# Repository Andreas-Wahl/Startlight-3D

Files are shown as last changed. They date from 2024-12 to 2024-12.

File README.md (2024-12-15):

# STARTAMPEL "Bären(n)keller" 🚦

## Project Overview 🏎️

In a private cellar bar that has been in existence for over two generations, originally named "Bärenkeller," a CARRERA® digital 132 racetrack was set up, and the first races were held. This quickly gained popularity among friends and acquaintances. As a result, the racetrack was gradually expanded, and possible extensions were discussed.

The idea of creating a custom starting light emerged because the original CARRERA® Startlight (30354) could not bridge three lanes (two lanes + pit lane). Additionally, the custom STARTAMPEL should not only display the start sequence with red lights but also indicate the race operation with green LEDs, the safety car/pace car operation, and a false start.

The idea was quickly taken up, the data signal was analyzed with an oscilloscope and data logger, and the development of hardware, software, and housing design was initiated.

In reference to the "Bärenkeller," which was renamed "Bären(n)keller" due to the expansion of the CARRERA® digital 132 racetrack, the custom starting light was also named "STARTAMPEL 'Bären(n)keller'."

The STARTAMPEL "Bären(n)keller" was so well received that the developer decided to produce a small quantity as "prototypes" and make the development available for non-commercial use.

## Licensing 📜

- **Electronics and Housing Design**: Released under the Creative Commons Attribution-NonCommercial-ShareAlike 4.0 International License (CC BY-NC-SA 4.0).
- **Software**: Released under the GNU Affero General Public License, Version 3.0 (AGPL-3.0).

## Repository Contents 📂

- **3D CAD Models**: The complete 3D CAD models for the STARTAMPEL "Bären(n)keller".
- **STL Files**: STL files for 3D printing the components.

## Getting Started 🚀

To get started with the project, clone the repository and follow the instructions in the documentation to set up the hardware and software.

```bash
git clone https://github.com/Andreas-Wahl/Startlight-3D.git

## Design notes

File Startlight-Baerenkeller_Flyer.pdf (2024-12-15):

# SLOTCAR STARTAMPEL „Bären(n)keller“

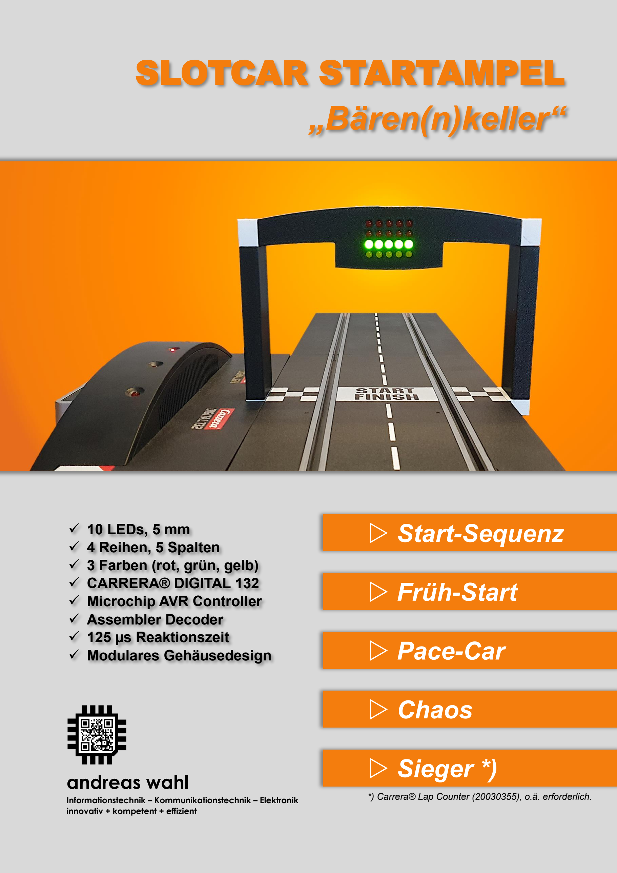
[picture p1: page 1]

# - Start-Sequenz

# - Früh-Start

# - Pace-Car

# - Sieger *)

# - Chaos

✓ 10 LEDs, 5 mm
✓ 4 Reihen, 5 Spalten
✓ 3 Farben (rot, grün, gelb) ✓ CARRERA® DIGITAL 132
✓ Microchip AVR Controller ✓ Assembler Decoder
✓ 125 µs Reaktionszeit
✓ Modulares Gehäusedesign

## andreas wahl

Informationstechnik – Kommunikationstechnik – Elektronik innovativ + kompetent + effizient

*) Carrera® Lap Counter (20030355), o.ä. erforderlich.

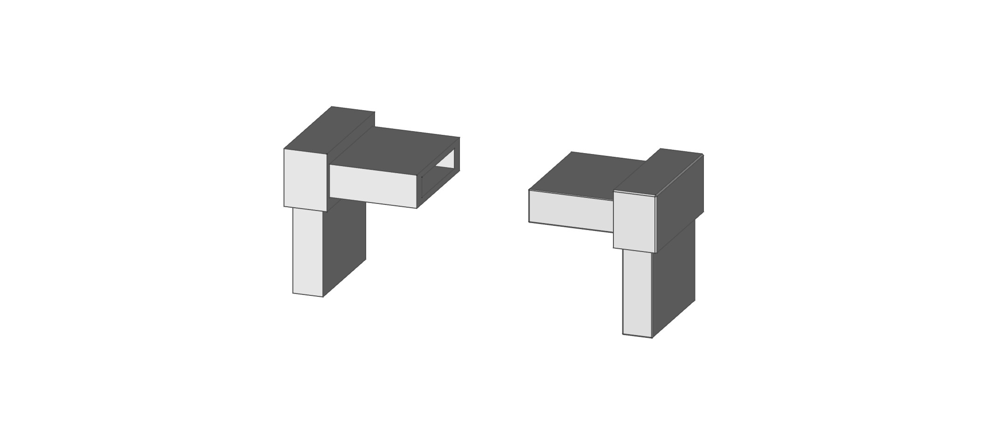
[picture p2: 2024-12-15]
#JPEG/Startlight-Baerenkeller_21_Winkel.jpeg

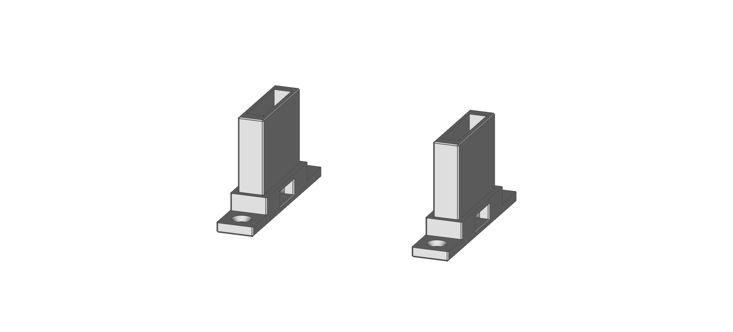
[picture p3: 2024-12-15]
#JPEG/Startlight-Baerenkeller_45_Fuesse_verschraubt.jpeg

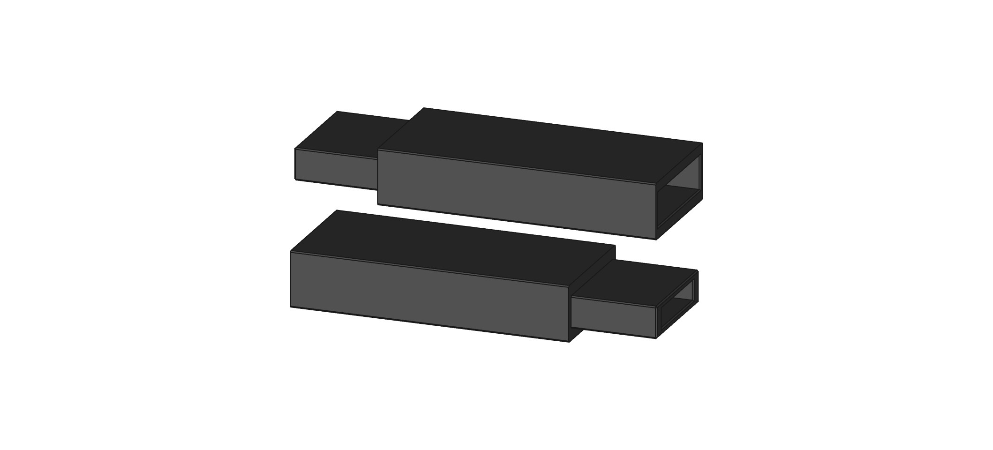
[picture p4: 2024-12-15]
#JPEG/Startlight-Baerenkeller_23_Verlaengerungen.jpeg

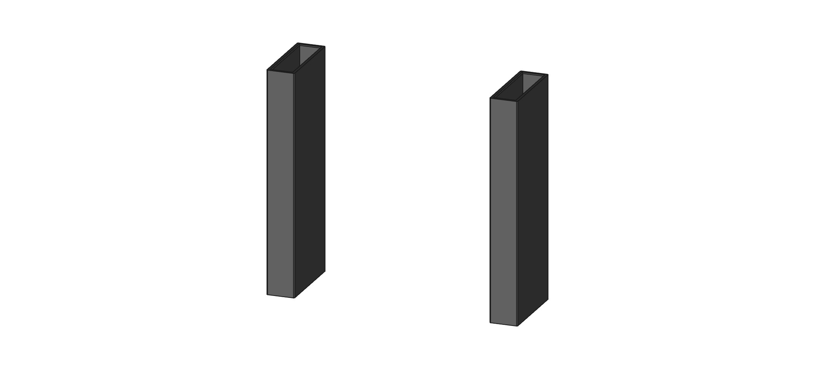
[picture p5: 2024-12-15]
#JPEG/Startlight-Baerenkeller_31_Saulen.jpeg

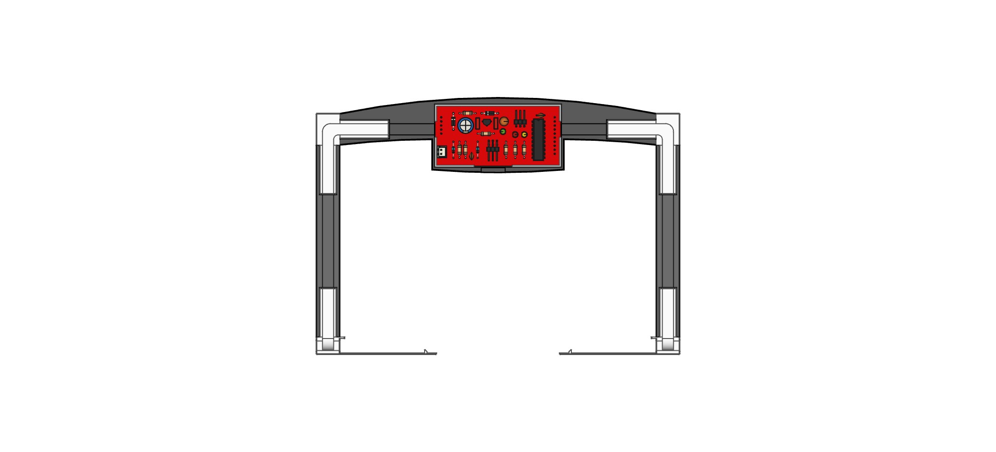
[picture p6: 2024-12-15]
#JPEG/Startlight-Baerenkeller_02_Schnitt_Rueckseite.jpeg

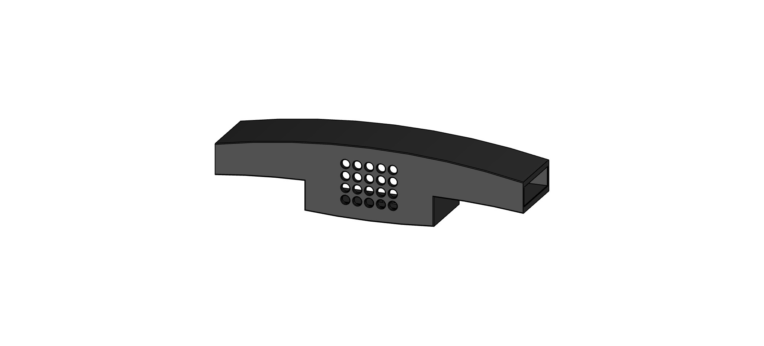
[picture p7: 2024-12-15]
#JPEG/Startlight-Baerenkeller_11_Bruecke_Grundform.jpeg

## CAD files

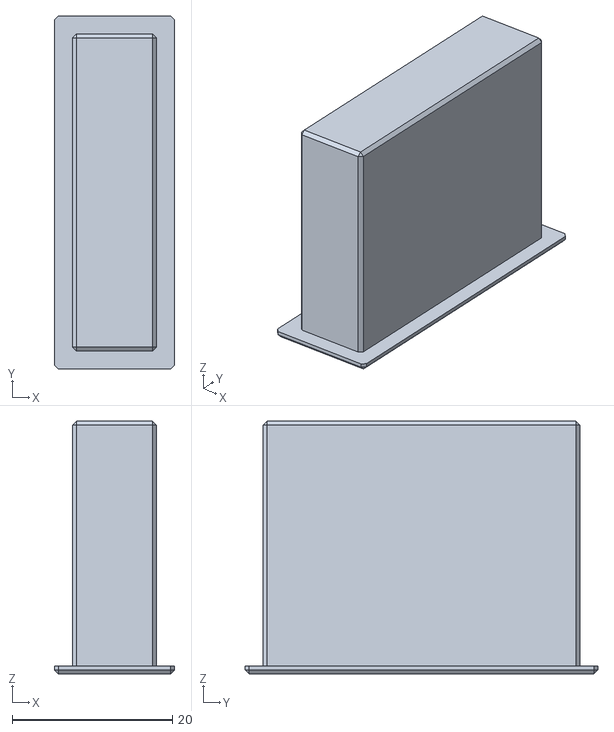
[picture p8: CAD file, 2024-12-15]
#STL/Startlight-Baerenkeller_44-Fuss_CU_links.stl
15.0 x 44.0 x 31.5

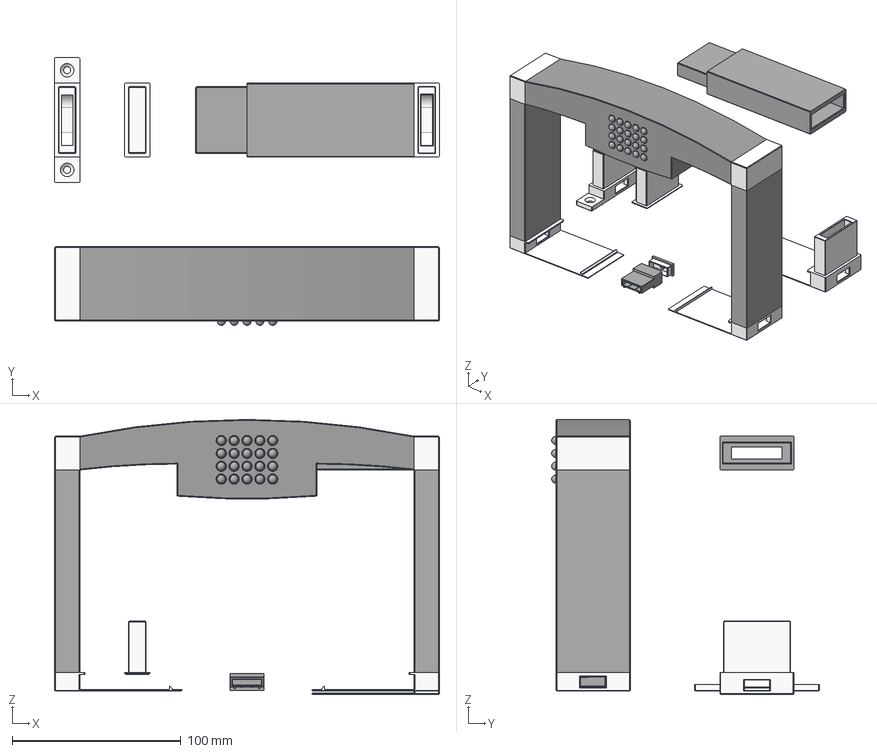
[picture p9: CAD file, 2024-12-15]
FreeCAD/Startlight-Baerenkeller.FCStd
228.0 x 158.6 x 162.9 mm
Bruecke_Grundform
Bruecke_Deckel
Bruecke_Platinenhalter
Winkel_rechts
Winkel_links
Verlaengerung
Saeule_rechts
Saeule_links
Fuss_Gerade_rechts
Fuss_Gerade_links
Fuss_CU_rechts
Fuss_CU_links
Fuss_geschraubt
Pcb_8670
R7_R_Axial_DIN0207_L63mm_D25mm_P1016mm_Horizontal_59bd9cc1ad034 x 7
D3_LED_D3.0mm_gn_1fa47e61fbaf001
J1_JST_B2B_XH_A_24b784548caa
D1_D_DO-41_SOD81_P10.16mm_Horizontal_290e6ff36fcd001 x 2
D7_LED_D3.0mm_ye_9d2be0ed744c001
C6_C_Disc_D50mm_W25mm_P500mm_e65bb01b6e083
C4_CP_Radial_Tantal_D55mm_P250mm_81b8040a8501
C2_C_Rect_L72mm_W25mm_P500mm_FKS2_FKP2_MKS2_MKP2_f287a4032b8a001 x 2
U1_TO-92_Wide_6a11e99f108c001
D6_LED_D3.0mm_986d951d84c007
D4_D_DO-35_SOD27_P10.16mm_Horizontal_10ecc1ea8124 x 2
U2_DIP-20_W7.62mm_8a95aeb67003
J3_PinHeader_1x03_P254mm_Horizontal_ee620f1cb55f001
C5_C_Disc_D50mm_W25mm_P250mm_856fdcf0def010
C1_CP_Radial_D100mm_P500mm_6f2c05164d2a001
J2_PinHeader_2x03_P254mm_Horizontal_d2f1fe9952c010
J4_PinSocket_1x10_P254mm_Vertical_49487ed71f7d001
J5_PinSocket_1x05_P254mm_Vertical_6526ee4f4357
Pcb_d933
D28_LED_D5.0mm_ye_dfcb4232a326 x 5
R14_R_Axial_DIN0207_L63mm_D25mm_P1016mm_Horizontal_cf2145029063 x 7
D10_LED_D5.0mm_rd_23c278344ce005 x 10
D21_LED_D5.0mm_gn_65f3b5c2c833 x 5
D8_D_DO-41_SOD81_P7.62mm_Horizontal_3af89f85bdd008
U3_DIP-16_W7.62mm_4ff0648cd1cf001
C7_CP_Radial_Tantal_D55mm_P250mm_4f9ef95a92da001
J7_PinHeader_1x05_P254mm_Vertical_de3b7650ac1e001
J6_PinHeader_1x10_P254mm_Vertical_46d302e49f012
5_LED_Abstandhalter
Stecker_Grundform
Stecker_Deckel

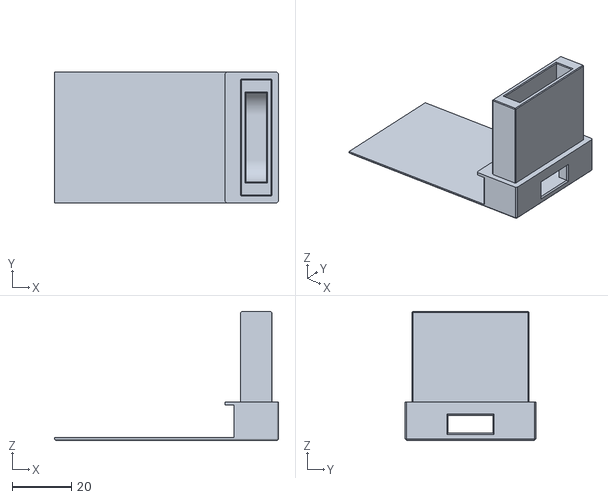
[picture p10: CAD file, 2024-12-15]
#STL/Startlight-Baerenkeller_43-Fuss_CU_rechts.stl
75.5 x 44.0 x 43.5

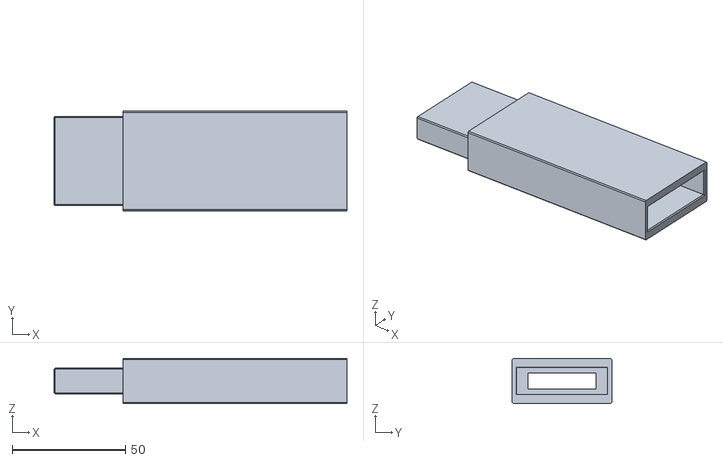
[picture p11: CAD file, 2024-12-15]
#STL/Startlight-Baerenkeller_23-Verlängerung.stl
129.5 x 44.0 x 20.0

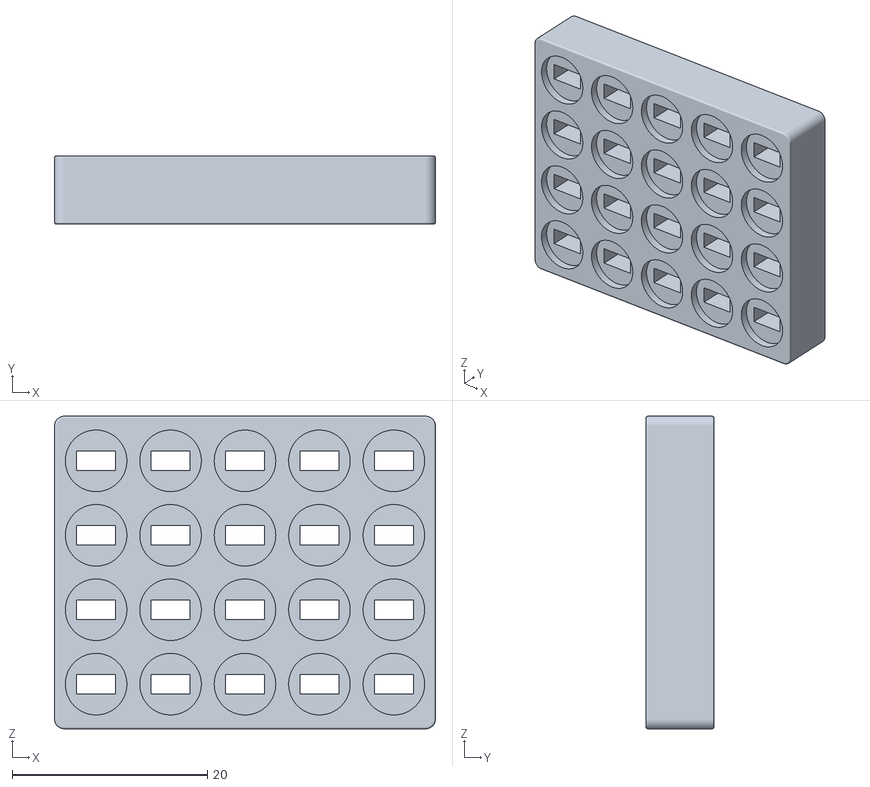
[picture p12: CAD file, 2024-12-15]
#STL/Startlight-Baerenkeller_51-LED-Abstandhalter.stl
39.0 x 7.00 x 32.0

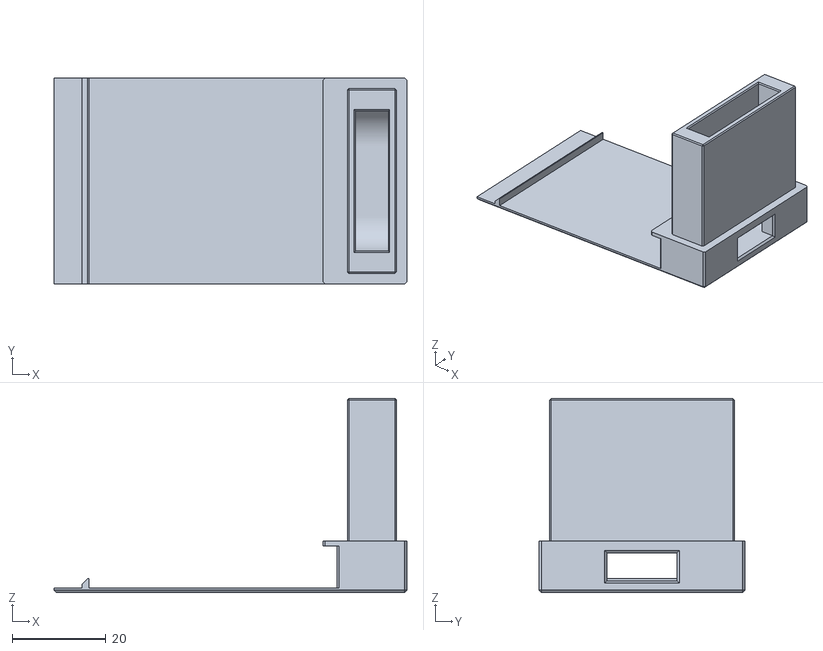
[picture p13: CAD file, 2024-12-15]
#STL/Startlight-Baerenkeller_41-Fuss_Gerade_rechts.stl
75.5 x 44.0 x 41.5

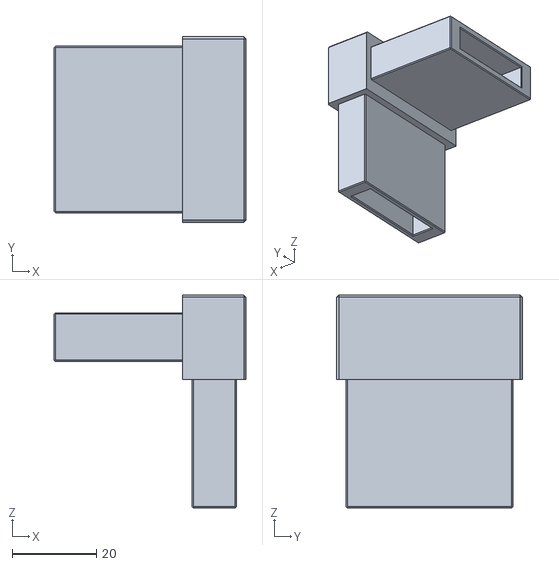
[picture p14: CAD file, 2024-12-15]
#STL/Startlight-Baerenkeller_21-Winkel-rechts.stl
45.5 x 44.0 x 50.5

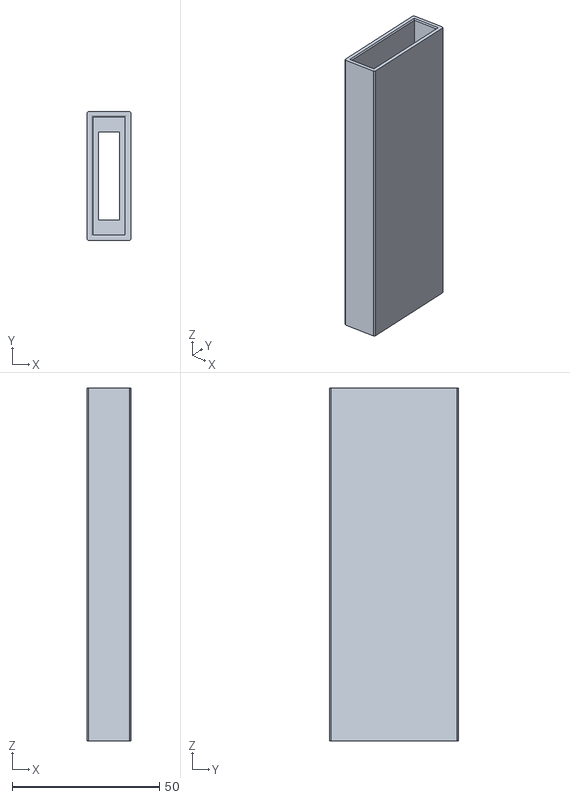
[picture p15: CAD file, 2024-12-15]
#STL/Startlight-Baerenkeller_31-Saeule-rechts.stl
15.0 x 44.0 x 120.0

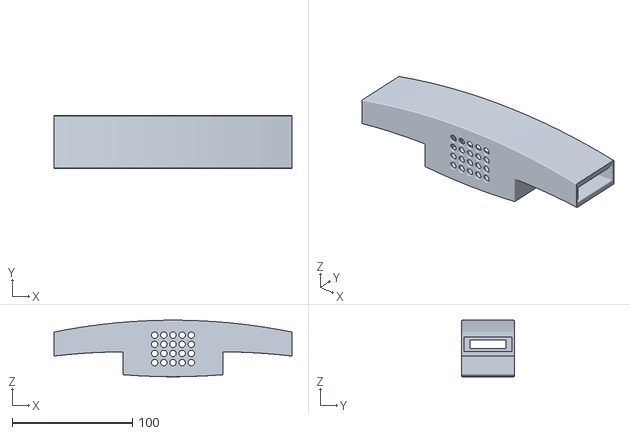
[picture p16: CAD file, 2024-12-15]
#STL/Startlight-Baerenkeller_11-Bruecke-Grundform.stl
198.0 x 44.0 x 47.1

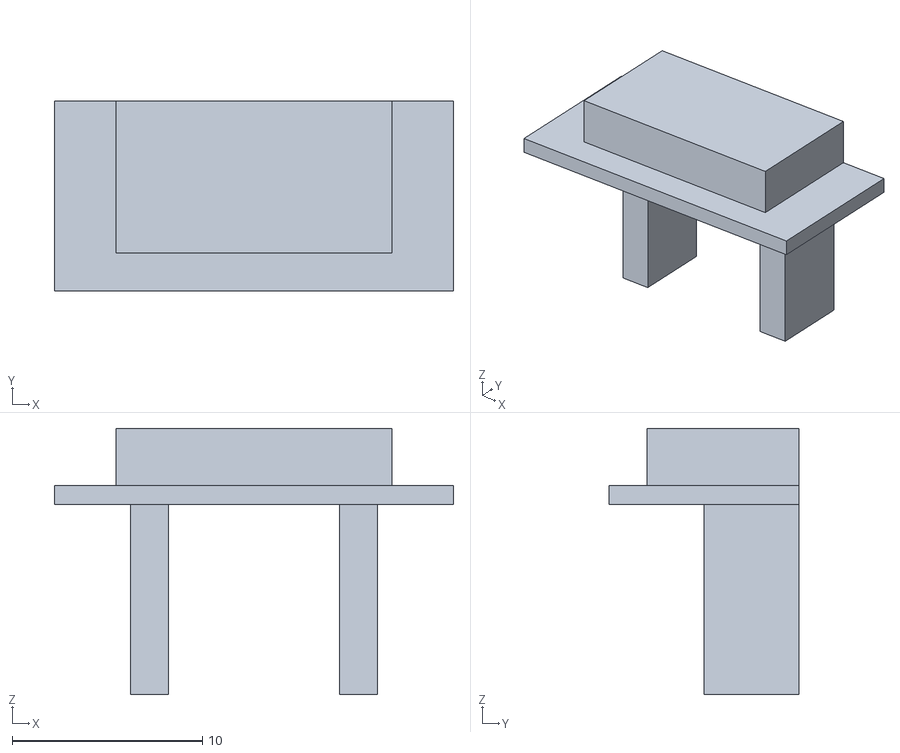
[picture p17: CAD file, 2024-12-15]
#STL/Startlight-Baerenkeller_13-Bruecke-Platinenhalter.stl
21.0 x 10.0 x 14.0

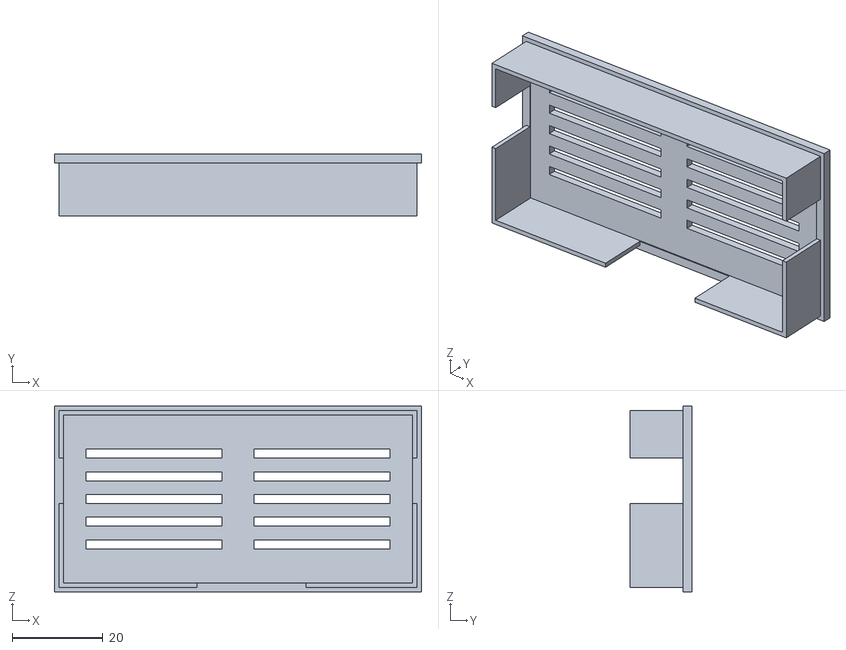
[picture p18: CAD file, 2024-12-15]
#STL/Startlight-Baerenkeller_12-Bruecke-Deckel.stl
81.0 x 13.8 x 41.0

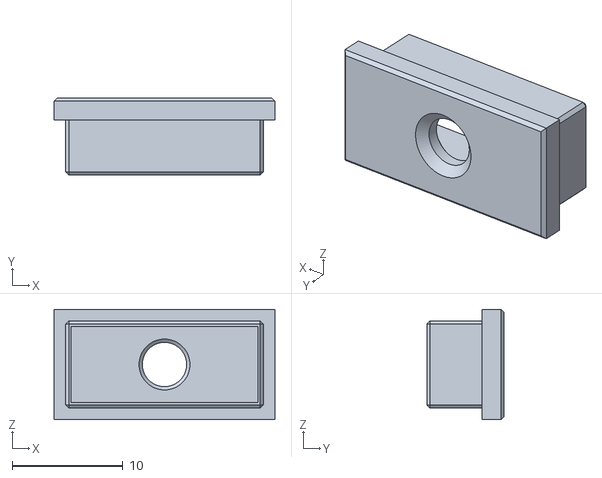
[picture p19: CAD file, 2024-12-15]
#STL/Startlight-Baerenkeller_62-Stecker-Deckel.stl
20.0 x 7.00 x 10.0

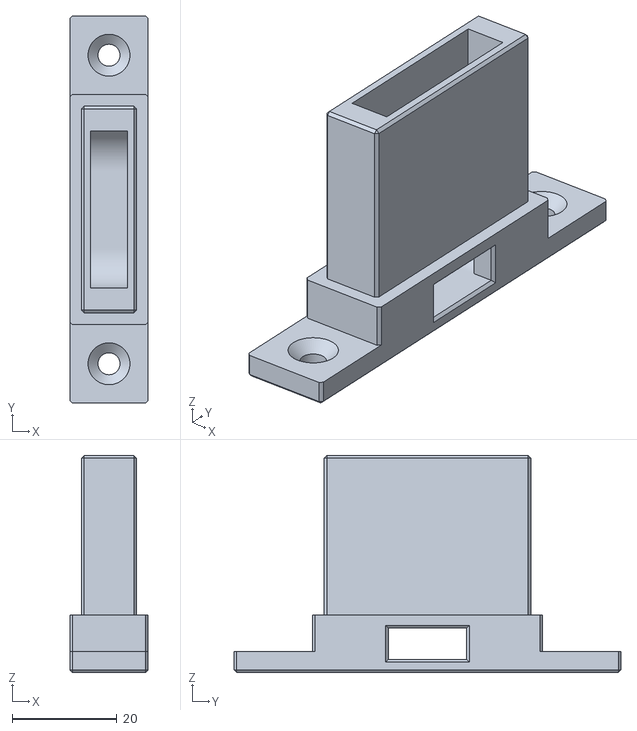
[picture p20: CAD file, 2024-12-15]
#STL/Startlight-Baerenkeller_45-Fuss_geschraubt.stl
15.0 x 74.0 x 41.5

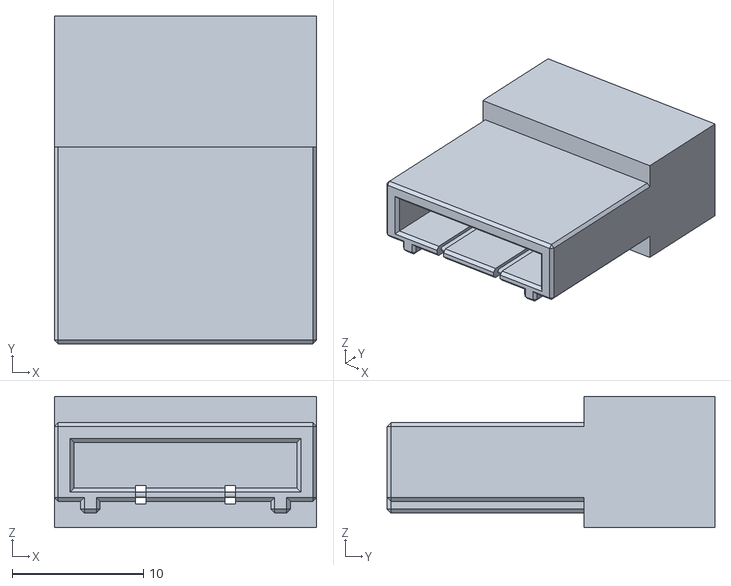
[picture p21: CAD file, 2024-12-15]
#STL/Startlight-Baerenkeller_61-Stecker-Grundform.stl
20.0 x 25.0 x 10.0

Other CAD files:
#STL/Startlight-Baerenkeller_22-Winkel-links.stl
#STL/Startlight-Baerenkeller_42-Fuss_Gerade_links.stl
#STL/Startlight-Baerenkeller_32-Saeule-links.stl

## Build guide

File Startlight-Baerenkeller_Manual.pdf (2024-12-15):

# SLOTCAR STARTAMPEL „Bären(n)keller“

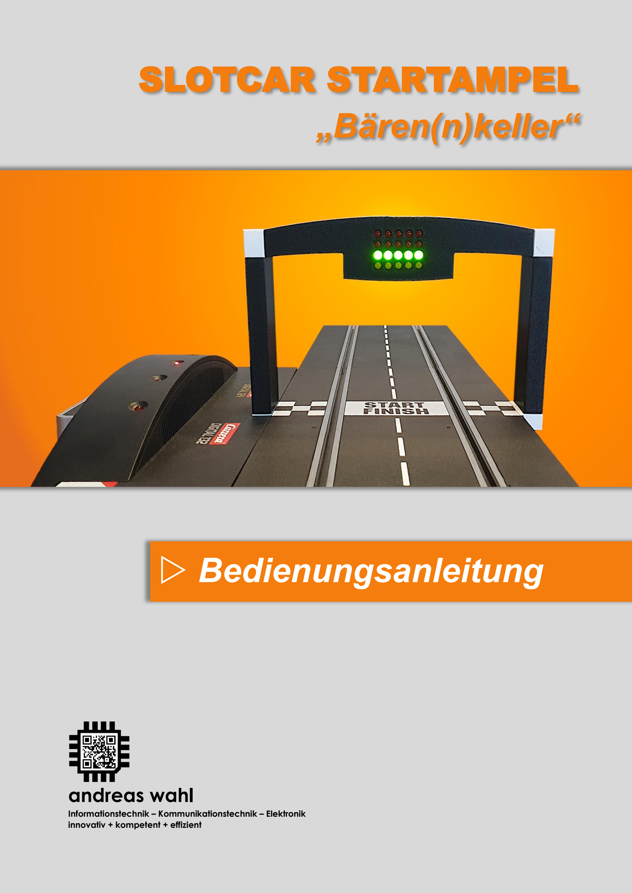
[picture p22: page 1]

SLOTCAR STARTAMPEL "Bären(n)keller" - Bedienungsanleitung

# - Bedienungsanleitung

## andreas wahl

Informationstechnik – Kommunikationstechnik – Elektronik innovativ + kompetent + effizient

# SLOTCAR STARTAMPEL

# „Bären(n)keller“

# Bedienungsanleitung

# Version 1.0 - 31.01.2024

Software-Version: 1.0
https://github.com/Andreas-Wahl/Startlight-SW
Hardware-Version: 1.3
https://github.com/Andreas-Wahl/Startlight-HW
Gehäuse-Version 1.0
https://github.com/Andreas-Wahl/Startlight-3D

## andreas wahl

Informationstechnik – Kommunikationstechnik – Elektronik innovativ + kompetent + effizient
https:/www.andreas-wahl.de/

### Inhaltsverzeichnis

### Idee und Namensgebung

In einer bereits über zwei Generationen
bestehenden | privaten | Kellerbar, | die
ursprünglich | den | Namen | „Bärenkeller“
erhalten hat, wurde eine CARRERA® digital 132 Rennbahn aufgebaut und die ersten Rennen ausgetragen.
Schnell | fand | dies | bei | Freunden | und
Bekannten großen Anklang. So wurde die Rennbahn sukzessive weiter ausgebaut und über mögliche Erweiterungen diskutiert.

So entstand auch die Idee einer eigenen Startampel, da die originale Startampel CARRERA® Startlight (30354) nicht über drei Fahrspuren (zwei Fahrspuren + Boxengasse) überbrücken kann. Weiter sollte die eigene Startampel nicht nur die Start-Sequenz über rote Anzeigen darstellen können, sondern auch den freigegebenen Rennbetrieb mit grünen LEDs, den Safety-Car-/Pace-Car-Betrieb und einen Frühstart anzeigen.

Kurzerhand wurde die Idee aufgegriffen, das Datensignal mit Oszilloskop und Datenlogger analysiert und die Entwicklung von Hardware, Software und Gehäuse-Design angestoßen.

In Bezug auf den „Bärenkeller“, welcher durch die Erweiterung der CARRERA® digital 132 Rennbahn zum „Bärennkeller“ umbenannt wurde, erhielt auch die selbst entwickelte
Startampel | den | Namen | „STARTAMPEL
„Bären(n)keller““.

Die STARTAMPEL „Bären(n)keller“ fand so großen Anklang, dass sich der Entwickler entschlossen hat, eine kleine Menge als
„Prototypen“ | zu | produzieren | und | die
Entwicklung für nicht kommerzielle Nutzung zur Verfügung zu stellen.

Die Elektronik und das Gehäusedesign sind unter der Creative Commons Version 4.0 Lizenz „Namensnennung, nicht kommerziell, Weitergabe unter gleichen Bedingungen (CC BY-NC-SA 4.0)“ und die Software unter der „GNU Affero General Public License, Version 3.0“ veröffentlicht.

1
In Verbindung mit der CARRERA® Control Unit (Art.-Nr.: 20030352).

### Technische Daten

Funktionen¹
:
- Startsequenz
- PACE CAR - Anzeige
- Frühstart - Anzeige
- CHAOS-/STOP - Anzeige
- Renn-Ende/Sieger - Anzeige²

Spannungsversorgung (aus Fahrleiter):
digital 132 | 14,8 V
digital 124 | 18,0 V

Stromaufnahme @ 14,8V (digital 132):
maximal: | 110 mA
bei Fahrbetrieb (grün) | 40 mA
bei Start/Chaos (alle rot) | 109 mA

Stromaufnahme @ 18V (digital 124):
maximal: | 135 mA
bei Fahrbetrieb (grün) | 50 mA
bei Start/Chaos (alle rot) | 132 mA

Decoder:
Assembler Software Decoder für Microchip/Atmel AVR ATtiny 2313
Reaktionszeit: | 125 µs

Abmessungen:
Höhe: | 161 cm
Tiefe: | 44 cm
Breite bei 2 Spuren | 228 cm
Breite bei 3 Spuren | 327 cm
Breite bei 4 Spuren | 426 cm

2 Zusätzlich mit dem CARRERA® Lap Counter (Art.-Nr.: 20030355).

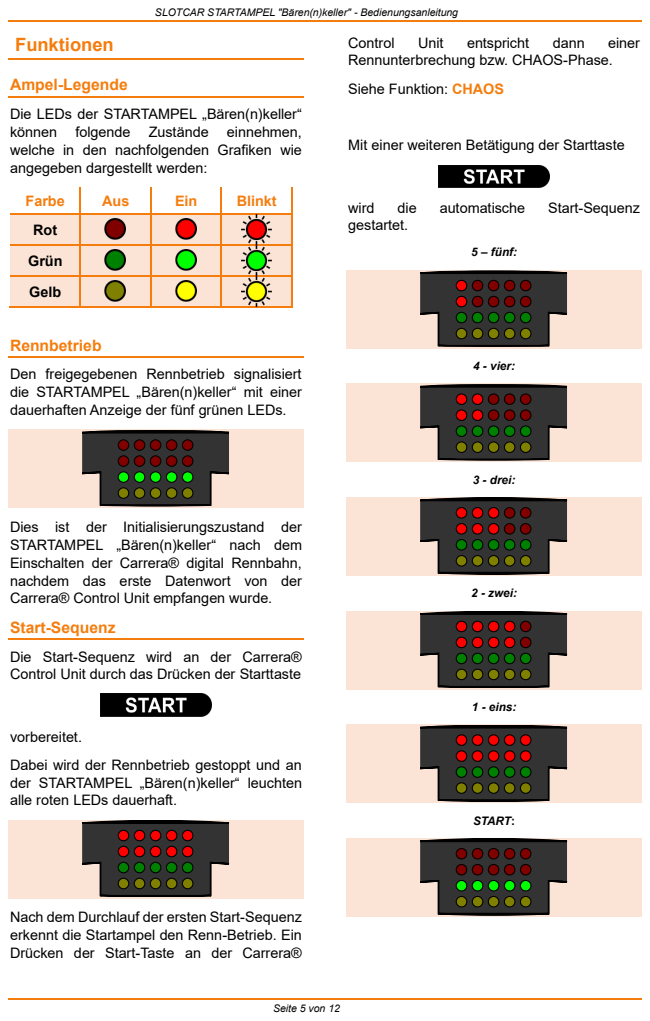
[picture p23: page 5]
Funktionen; Ampel-Legende; können; folgende; Zustände; einnehmen,; Farbe; Aus; Ein; Blinkt; Rot; Grün; Gelb; Rennbetrieb; Dies; ist; der Initialisierungszustand; der; Start-Sequenz; vorbereitet.; Control; Unit; entspricht; dann; einer; wird; die; automatische; gestartet.; 5 – fünf:; 4 - vier:; 3 - drei:; 2 - zwei:; 1 - eins:; START:

Rennunterbrechung bzw. CHAOS-Phase.

Siehe Funktion: CHAOS

Die LEDs der STARTAMPEL „Bären(n)keller“
welche in den nachfolgenden Grafiken wie
angegeben dargestellt werden:

Mit einer weiteren Betätigung der Starttaste

Den freigegebenen Rennbetrieb signalisiert
die STARTAMPEL „Bären(n)keller“ mit einer
dauerhaften Anzeige der fünf grünen LEDs.

STARTAMPEL „Bären(n)keller“ nach dem
Einschalten der Carrera® digital Rennbahn,
nachdem das erste Datenwort von der
Carrera® Control Unit empfangen wurde.

Die Start-Sequenz wird an der Carrera®
Control Unit durch das Drücken der Starttaste

Dabei wird der Rennbetrieb gestoppt und an
der STARTAMPEL „Bären(n)keller“ leuchten
alle roten LEDs dauerhaft.

Nach dem Durchlauf der ersten Start-Sequenz
erkennt die Startampel den Renn-Betrieb. Ein
Drücken der Start-Taste an der Carrera®

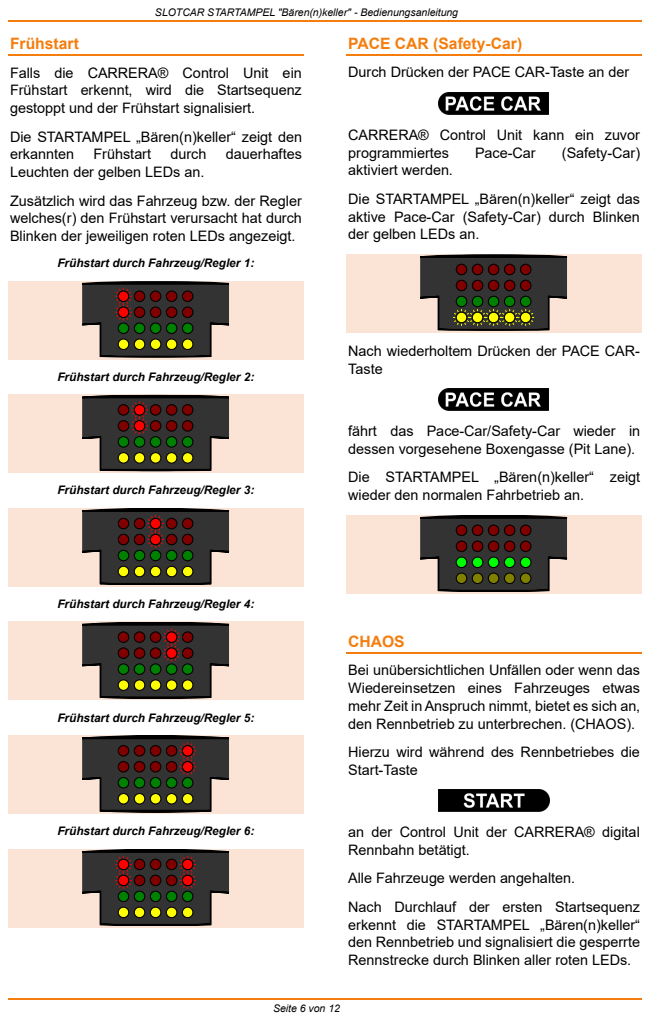
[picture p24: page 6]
Frühstart; erkannten; durch; dauerhaftes; programmiertes; Pace-Car; (Safety-Car); CHAOS

PACE CAR (Safety-Car)

Falls die CARRERA® Control Unit ein
Frühstart erkennt, wird die Startsequenz
gestoppt und der Frühstart signalisiert.

Durch Drücken der PACE CAR-Taste an der

Die STARTAMPEL „Bären(n)keller“ zeigt den
Leuchten der gelben LEDs an.

CARRERA® Control Unit kann ein zuvor
aktiviert werden.

Zusätzlich wird das Fahrzeug bzw. der Regler
welches(r) den Frühstart verursacht hat durch
Blinken der jeweiligen roten LEDs angezeigt.

Die STARTAMPEL „Bären(n)keller“ zeigt das
aktive Pace-Car (Safety-Car) durch Blinken
der gelben LEDs an.

Frühstart durch Fahrzeug/Regler 1:

Nach wiederholtem Drücken der PACE CAR-
Taste

Frühstart durch Fahrzeug/Regler 2:

fährt das Pace-Car/Safety-Car wieder in
dessen vorgesehene Boxengasse (Pit Lane).

Die STARTAMPEL „Bären(n)keller“ zeigt
wieder den normalen Fahrbetrieb an.

Frühstart durch Fahrzeug/Regler 3:

Frühstart durch Fahrzeug/Regler 4:

Bei unübersichtlichen Unfällen oder wenn das
Wiedereinsetzen eines Fahrzeuges etwas
mehr Zeit in Anspruch nimmt, bietet es sich an,
den Rennbetrieb zu unterbrechen. (CHAOS).

Frühstart durch Fahrzeug/Regler 5:

Hierzu wird während des Rennbetriebes die
Start-Taste

Frühstart durch Fahrzeug/Regler 6:

an der Control Unit der CARRERA® digital
Rennbahn betätigt.

Alle Fahrzeuge werden angehalten.

Nach Durchlauf der ersten Startsequenz
erkennt die STARTAMPEL „Bären(n)keller“
den Rennbetrieb und signalisiert die gesperrte
Rennstrecke durch Blinken aller roten LEDs.

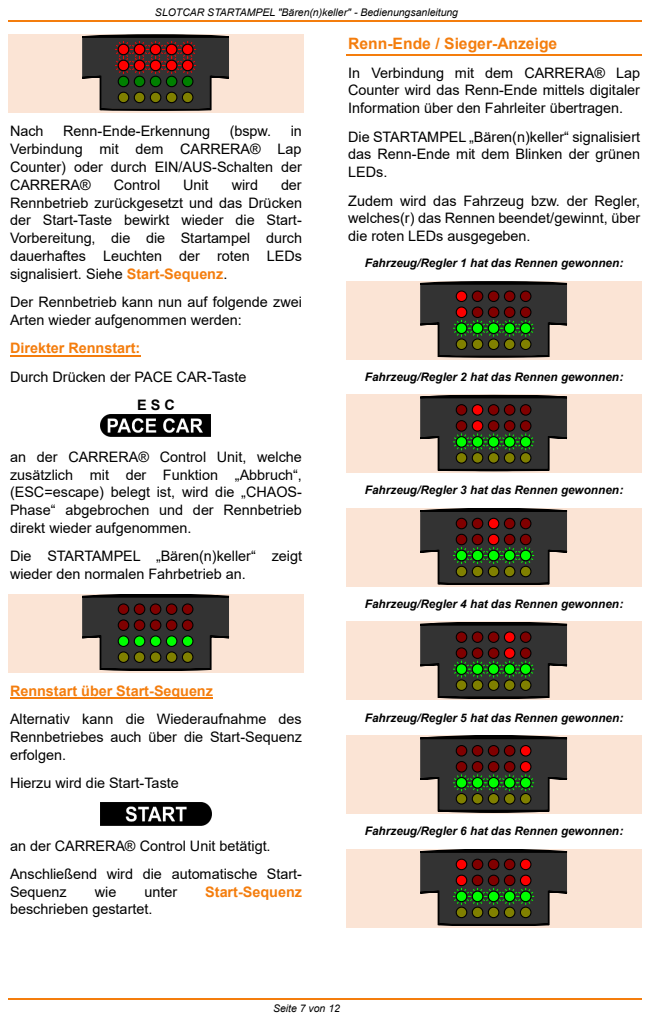
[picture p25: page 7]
Nach; Renn-Ende-Erkennung; (bspw.; Verbindung; mit; dem; CARRERA®; Lap; Control; Unit; wird; der; dauerhaftes; Leuchten; roten; LEDs; Direkter Rennstart:; zusätzlich; Funktion; „Abbruch“,; Sequenz; wie; unter; Start-Sequenz

Renn-Ende / Sieger-Anzeige

In Verbindung mit dem CARRERA® Lap
Counter wird das Renn-Ende mittels digitaler
Information über den Fahrleiter übertragen.

Counter) oder durch EIN/AUS-Schalten der
Rennbetrieb zurückgesetzt und das Drücken
der Start-Taste bewirkt wieder die Start-
Vorbereitung, die die Startampel durch
signalisiert. Siehe Start-Sequenz.

Die STARTAMPEL „Bären(n)keller“ signalisiert
das Renn-Ende mit dem Blinken der grünen
LEDs.

Zudem wird das Fahrzeug bzw. der Regler,
welches(r) das Rennen beendet/gewinnt, über
die roten LEDs ausgegeben.

Fahrzeug/Regler 1 hat das Rennen gewonnen:

Der Rennbetrieb kann nun auf folgende zwei
Arten wieder aufgenommen werden:

Durch Drücken der PACE CAR-Taste

Fahrzeug/Regler 2 hat das Rennen gewonnen:

an der CARRERA® Control Unit, welche
(ESC=escape) belegt ist, wird die „CHAOS-
Phase“ abgebrochen und der Rennbetrieb
direkt wieder aufgenommen.

Fahrzeug/Regler 3 hat das Rennen gewonnen:

Die STARTAMPEL „Bären(n)keller“ zeigt
wieder den normalen Fahrbetrieb an.

Fahrzeug/Regler 4 hat das Rennen gewonnen:

Rennstart über Start-Sequenz

Alternativ kann die Wiederaufnahme des
Rennbetriebes auch über die Start-Sequenz
erfolgen.

Fahrzeug/Regler 5 hat das Rennen gewonnen:

Hierzu wird die Start-Taste

Fahrzeug/Regler 6 hat das Rennen gewonnen:

an der CARRERA® Control Unit betätigt.

Anschließend wird die automatische Start-
beschrieben gestartet.

### Aufbau der STARTAMPEL

Die STARTAMPEL „Bären(n)keller ist modular
aufgebaut | und | kann | mittels | optionaler
Verlängerungen zwei, drei, vier oder mehrere Fahrspuren überbrücken.

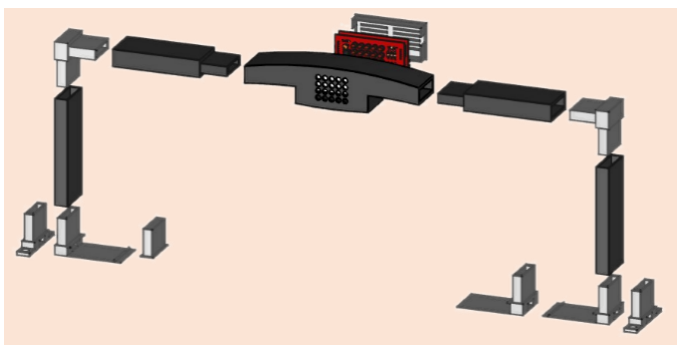
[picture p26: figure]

Verschiedene Montagefüße erlauben die Befestigung an

- einer Standardgeraden,
- der CARRERA ® Control Unit (Start/Ziel-Linie),
- oder per Verschraubung auf einer Montageplatte.

Die STARTAMPEL „Bären(n)keller“ kann somit nahezu jedem Aufbau der Rennstrecke flexibel angepasst werden.

Ampel-Brücke

Die Ampel-Brücke ist das grundlegende
Element | und | Gesicht | der | Start-Ampel
„Bären(n)keller“.

Durch die Brücke wird die Breite einer
Standard-Geraden | (zwei | Fahrspuren)
überbrückt.

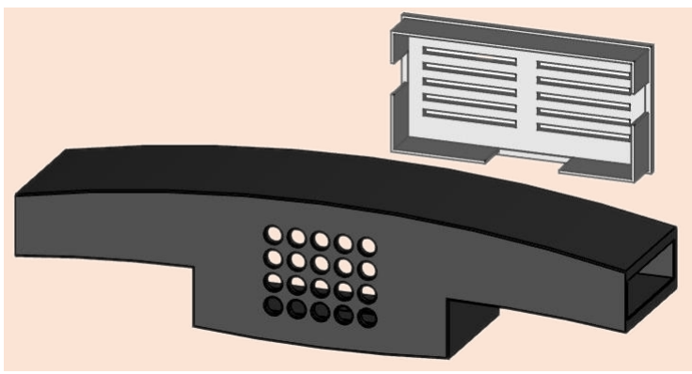
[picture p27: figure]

Nach dem Einsetzen der Elektronik und dem
Durchführen | und | Anschließen | der
Versorgungsleitung wird der Deckel rückseitig aufgesteckt.

Elektronik

Die Elektronik besteht aus zwei Platinen.

Eine Platine enthält den Microcontroller und die zur Auswertung des Manchester-Signals erforderlichen Komponenten. Die andere Platine enthält die LEDs, die Treiber und deren notwendiger Beschaltung.

Beide Platinen werden jeweils rückseitig zusammengesteckt.

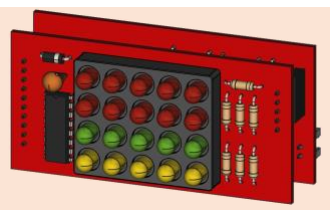
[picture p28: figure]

Die Elektronik wird mit den LEDs voran in die Brücke der STARTAMPEL „Bären(n)keller“ so eingesetzt, dass die LEDs durch die dafür vorgesehenen Löcher ragen. Die roten LED-Reihen zeigen dabei nach oben.

Verlängerungen [optional]

Mit | den | optionalen | waagerechten
Verlängerungen kann die Brücke um jeweils eine Fahrspurbreite erweitert werden.

Die Verlängerungen sind identisch und können sowohl rechts als auch links der Brücke angebracht werden.

Winkel-Verbinder

Zur Verbindung der senkrechten Säulen mit der Ampel-Brücke bzw. den Verlängerungen dienen die folgenden Winkelverbinder.

Säulen

Die senkrechten Säulen werden mit den
Winkelverbindern | und | mit | den | Füßen
verbunden.

Füße

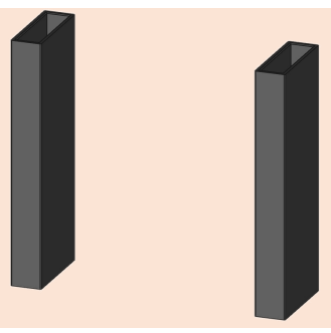
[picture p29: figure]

Montage an Standardgeraden

Zur Befestigung an einer Standardgeraden, bspw. direkt nach der CARRERA® Control Unit stehen L-Füße mit Arretierung zur Verfügung.

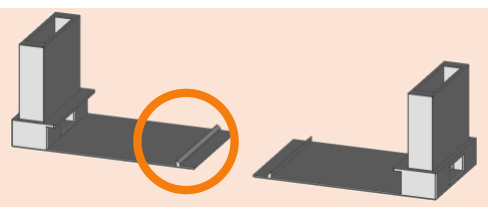
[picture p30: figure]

Diese L-Füße werden von der Seite an die Fahrbahn gesteckt und rasten unterhalb der Fahrbahn ein.

So hat die STARTAMPEL „Bären(n)keller den besten Halt.

Montage an Control Unit

Um die STARTAMPEL “Bären(n)keller“ direkt an der Start-/Ziellinie der CARRERA® Control Unit anzubringen, werden angepasste Füße benötigt.

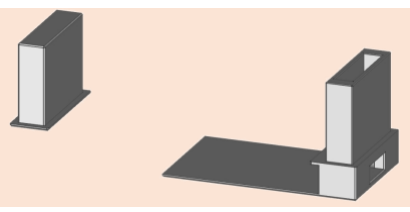
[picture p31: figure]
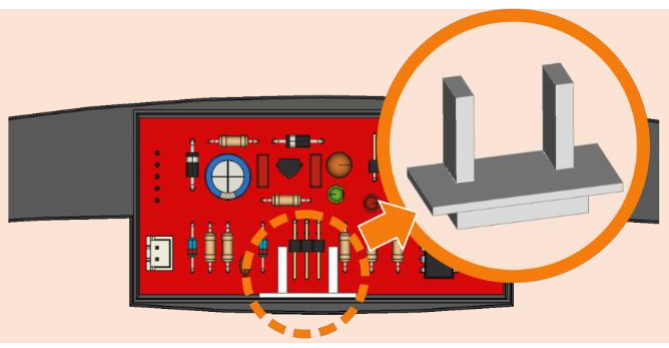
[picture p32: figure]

Auf der linken Seite wird ein „Blindstopfen“ benötigt, da hier die Ampel auf dem Randstreifen aufliegt.
Zur weiteren Befestigung kann hier bei Bedarf doppelseitiges Klebeband oder Klettstreifen verwendet werden.

Die rechte Seite kann mit einem L-Fuß unter die Fahrbahn gesteckt werden, so dass hier ein Halt gegen Umkippen gegeben ist. Aufgrund der Abdeckung der Verdrahtung der
CARRERA® | Control | Unit | ist | eine
Arretierungsmöglichkeit hier nicht gegeben.

Montage mit Schrauben

Alternativ kann mittels schraubbarer Füße auch die direkte Befestigung auf einer Montageplatte erfolgen.

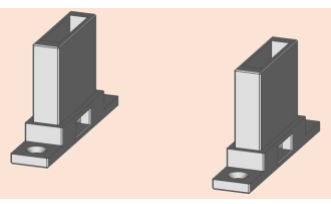
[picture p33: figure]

Dies eignet sich insbesondere dann, wenn mehrere Fahrspuren überbrückt werden sollen oder aufgrund des Aufbaus der Rennstrecke ein Unterschieben mittels L-Füßen nicht möglich ist.

Steckverbinder

Für den Anschluss an der CARRERA® Control Unit oder einer CARRERA® Adapter Unit wurde ein passender Anschlussstecker entworfen.

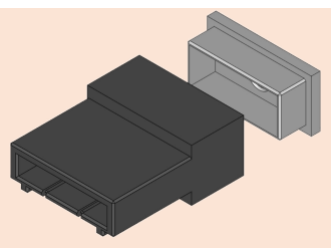
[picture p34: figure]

Platinenhalter

Um ein zurückschieben der Platinen und damit der LED-Anzeige zu verhindern, wird der Platinenhalter in die Aussparung des ISP-Anschlusses eingesetzt.

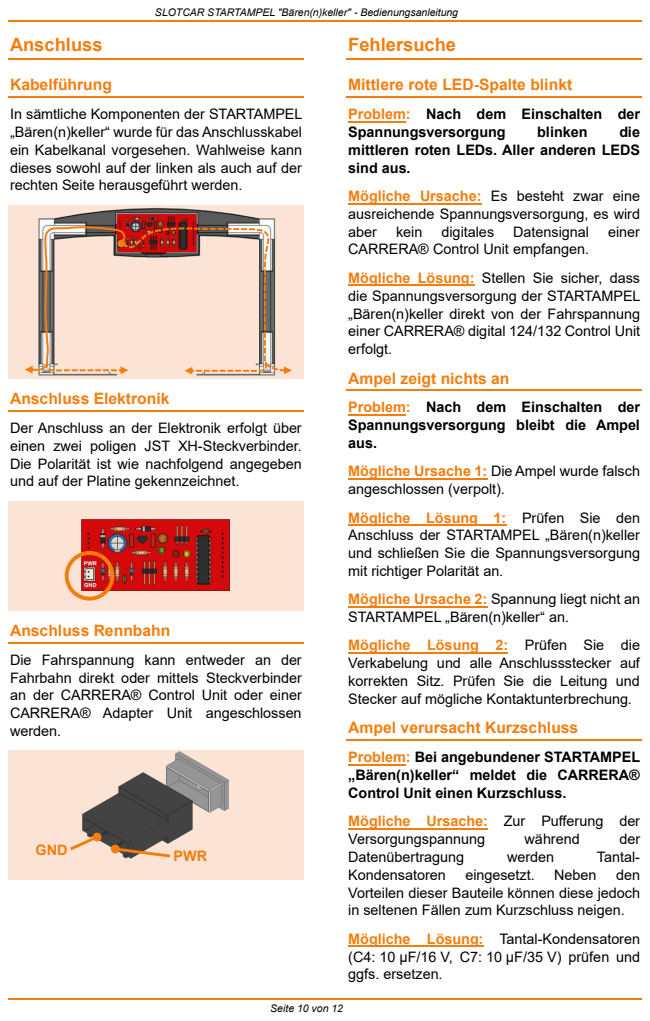
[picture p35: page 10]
Anschluss; Kabelführung; Anschluss Elektronik; Anschluss Rennbahn; Fehlersuche; Spannungsversorgung; blinken; die; aber; kein; digitales; Datensignal; einer; Mögliche; Lösung; Prüfen; Sie; Versorgungspannung; während; der; Datenübertragung; werden; Tantal-; Kondensatoren; eingesetzt.; Neben; den; Lösung: Tantal-Kondensatoren; GND; PWR

Mittlere rote LED-Spalte blinkt

In sämtliche Komponenten der STARTAMPEL
„Bären(n)keller“ wurde für das Anschlusskabel
ein Kabelkanal vorgesehen. Wahlweise kann
dieses sowohl auf der linken als auch auf der
rechten Seite herausgeführt werden.

Problem: Nach dem Einschalten der
mittleren roten LEDs. Aller anderen LEDS
sind aus.

Mögliche Ursache: Es besteht zwar eine
ausreichende Spannungsversorgung, es wird
CARRERA® Control Unit empfangen.

Mögliche Lösung: Stellen Sie sicher, dass
die Spannungsversorgung der STARTAMPEL
„Bären(n)keller direkt von der Fahrspannung
einer CARRERA® digital 124/132 Control Unit
erfolgt.

Ampel zeigt nichts an

Spannungsversorgung bleibt die Ampel
aus.

Der Anschluss an der Elektronik erfolgt über
einen zwei poligen JST XH-Steckverbinder.
Die Polarität ist wie nachfolgend angegeben
und auf der Platine gekennzeichnet.

Mögliche Ursache 1: Die Ampel wurde falsch
angeschlossen (verpolt).

Mögliche Lösung 1: Prüfen Sie den
Anschluss der STARTAMPEL „Bären(n)keller
und schließen Sie die Spannungsversorgung
mit richtiger Polarität an.

Mögliche Ursache 2: Spannung liegt nicht an
STARTAMPEL „Bären(n)keller“ an.

Verkabelung und alle Anschlussstecker auf
korrekten Sitz. Prüfen Sie die Leitung und
Stecker auf mögliche Kontaktunterbrechung.

Die Fahrspannung kann entweder an der
Fahrbahn direkt oder mittels Steckverbinder
an der CARRERA® Control Unit oder einer
CARRERA® Adapter Unit angeschlossen
werden.

Ampel verursacht Kurzschluss

Problem: Bei angebundener STARTAMPEL
„Bären(n)keller“ meldet die CARRERA®
Control Unit einen Kurzschluss.

Mögliche Ursache: Zur Pufferung der
Vorteilen dieser Bauteile können diese jedoch
in seltenen Fällen zum Kurzschluss neigen.

(C4: 10 µF/16 V, C7: 10 µF/35 V) prüfen und
ggfs. ersetzen.

### Ergänzende Informationen

Carrera Toys GmbH

- CARRERA Toys GmbH
https://carrera-toys.com/
- CARRERA® digital 132
https://carrera-toys.com/digital-132
- CARRERA® digital 124
https://carrera-toys.com/digital-124
- CARRERA® Control Unit (20030352)
https://carrera-toys.com/product/20030352-control-unit
- CARRERA® Startlight (20030354)
https://carrera-toys.com/product/20030354-startlight
- CARRERA® Lap Counter (20030355)
https://carrera-toys.com/product/20030355-lap-counter
- CARRERA® Adapter Unit (20030360)
https://carrera-toys.com/de/product/20030360-adapterunit (https://carrera-toys.com/de/product/20030360-adapter-unit)
Entwickler-Tools
- KiCAD EDA Suite
Schaltplan und Platinenlayout
https://www.kicad.org/
- Analog Devices LTspice
Simulation von elektronischen Schaltungen
https://www.analog.com/en/design-center/design-toolsand-calculators/ltspice-simulator.html (https://www.analog.com/en/design-center/design-tools-and-calculators/ltspice-simulator.html)
- Microchip Studio
Software-Entwicklung für Microcontroller ATmega/ATtiny in Assembler und C
https://www.microchip.com/en-us/toolsresources/develop/microchip-studio (https://www.microchip.com/en-us/tools-resources/develop/microchip-studio)
- FreeCAD
Parametrische 3D-Konstruktionen
https://www.freecadweb.org/
- Ultimaker Cura
3D printing Software / Slicer
https://ultimaker.com/software/ultimaker-cura/
Ähnliche Projekte
- Stephan Heß
http://slotbaer.de/carrera-digital-124-132.html
- Dipl. Ing. Peter Niehues
http://www.wasserstoffe.de/carrera-hacks/

### Entwickler und Herausgeber

## andreas wahl

Informationstechnik – Kommunikationstechnik – Elektronik innovativ + kompetent + effizient
https://www.andreas-wahl.de/

STARTAMPEL – Bären(n)keller auf GitHub:

- Software
https://github.com/Andreas-Wahl/Startlight-SW
- Hardware
https://github.com/Andreas-Wahl/Startlight-HW
- Gehäuse & Stecker
https://github.com/Andreas-Wahl/Startlight-3D

STARTAMPEL – Bären(n)keller auf Thingiverse:

- Gehäuse
https://www.thingiverse.com/thing:6443510
- Stecker
https://www.thingiverse.com/thing:6444956

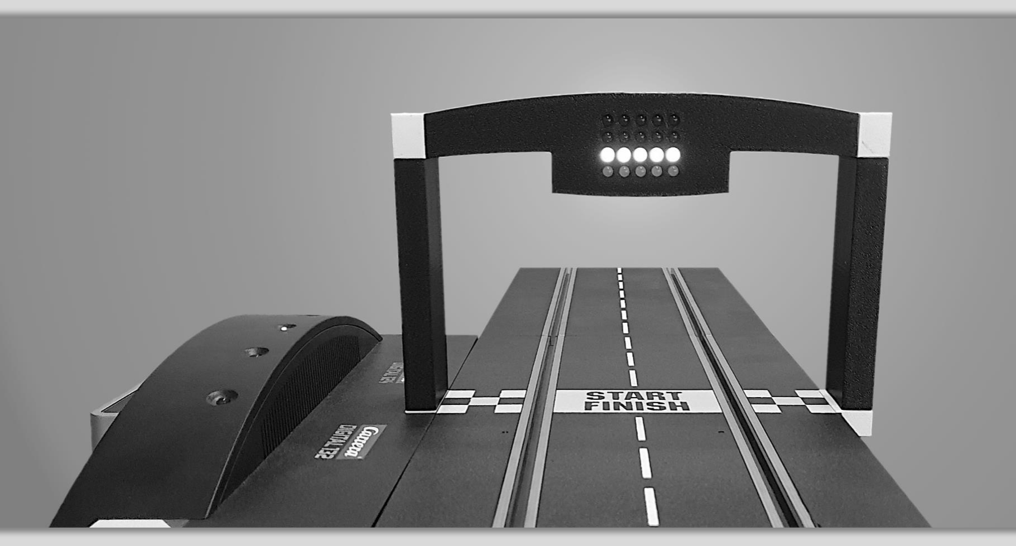
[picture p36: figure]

## andreas wahl

Informationstechnik – Kommunikationstechnik – Elektronik innovativ + kompetent + effizient
